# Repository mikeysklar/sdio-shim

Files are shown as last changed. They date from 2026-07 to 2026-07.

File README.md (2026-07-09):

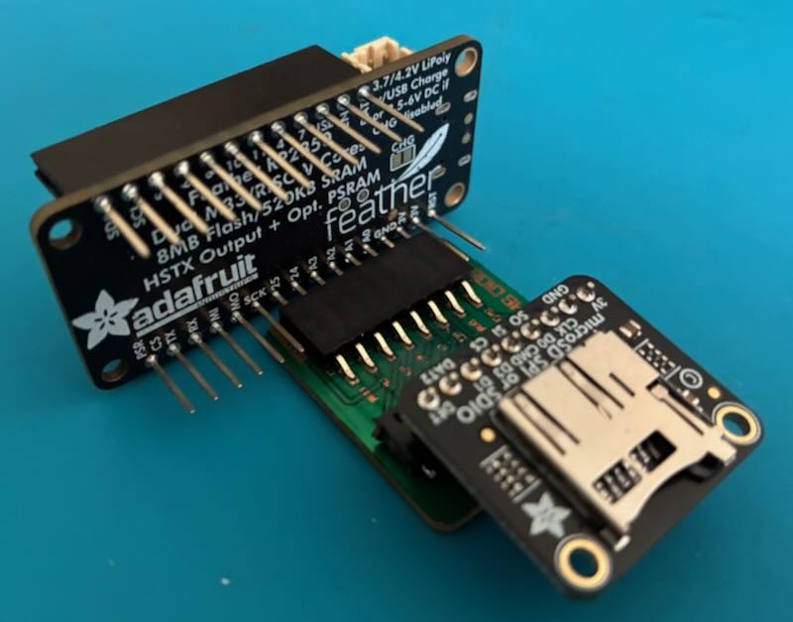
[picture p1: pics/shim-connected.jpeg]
Shim connected to a Feather


# sdio-shim

A direct-connect shim PCB that mates the Adafruit SDIO microSD breakout to a Feather — no breadboard required.

## About

A simple **passive shim** that routes a Feather's analog-rail pins to an SDIO microSD breakout (Adafruit **#4682** or a fork of it), so a stock 4-bit SDIO card hangs off any Feather **without eating the SPI, UART, or I2C buses**.

No active parts. It's a router: Feather header on one side, breakout connector on the other, eight nets between them. The shim itself carries **zero components** — the #4682 already provides the pull-ups, bypass/bulk caps, and card-detect resistor the SDIO spec requires.

Design files are in [`kicad/`](kicad/).

## Feather pinout

Chosen so the six SD logic lines land on **contiguous** Feather positions (A0→D25) while leaving every labeled bus free.

| Feather | GPIO | SDIO signal | Notes |
|---|:----:|---|---|
| 3V | — | Power | |
| GND | — | Ground | |
| A0 | 26 | DAT0 | data block **must stay consecutive** (PIO) |
| A1 | 27 | DAT1 | |
| A2 | 28 | DAT2 | |
| A3 | 29 | DAT3 | |
| D24 | 24 | CLK | any GPIO — placed here to stay on-rail |
| D25 | 25 | CMD | |

**Freed for peripherals:** SCK/MOSI/MISO (GPIO22/23/20 — full SPI bus), TX/RX (GPIO0/1 — UART0), SDA/SCL (I2C, other rail). Card-detect is **dropped** (leave the breakout's DET pad unconnected).

D24/D25 carry CLK/CMD because they sit physically right after A0–A3 on the rail and are plain GPIOs — so the SD wiring stays crossing-free and costs you nothing labeled. TX/RX would work electrically but would burn the UART.

### CircuitPython usage

```python
import board, sdioio, storage
sd = sdioio.SDCard(
    clock=board.D24,
    command=board.D25,
    data=(board.A0, board.A1, board.A2, board.A3),
    frequency=37_500_000,
)
storage.mount(storage.VfsFat(sd), "/sd")
```

## Throughput

Measured bulk transfer over 4-bit SDIO in CircuitPython, using the [Adafruit benchmark setup](https://learn.adafruit.com/microsd-optimization-circuitpython/benchmark-setup). Both boards use this shim with the [Adafruit MicroSD SPI/SDIO breakout (#4682)](https://www.adafruit.com/product/4682).

| Chip | Board | Bus  | Clock (MHz) | Write (MB/s) | Read (MB/s) |
|---|---|---|:---:|:---:|:---:|
| RP2350 | Feather + SDIO Shim  | SDIO | 37.5 | 14.9 | 13.0 |
| ESP32-S3 | Feather + SDIO Shim  | SDIO | 40 | 4.5 | 7.1 |

## Photos & board files

### Assembled
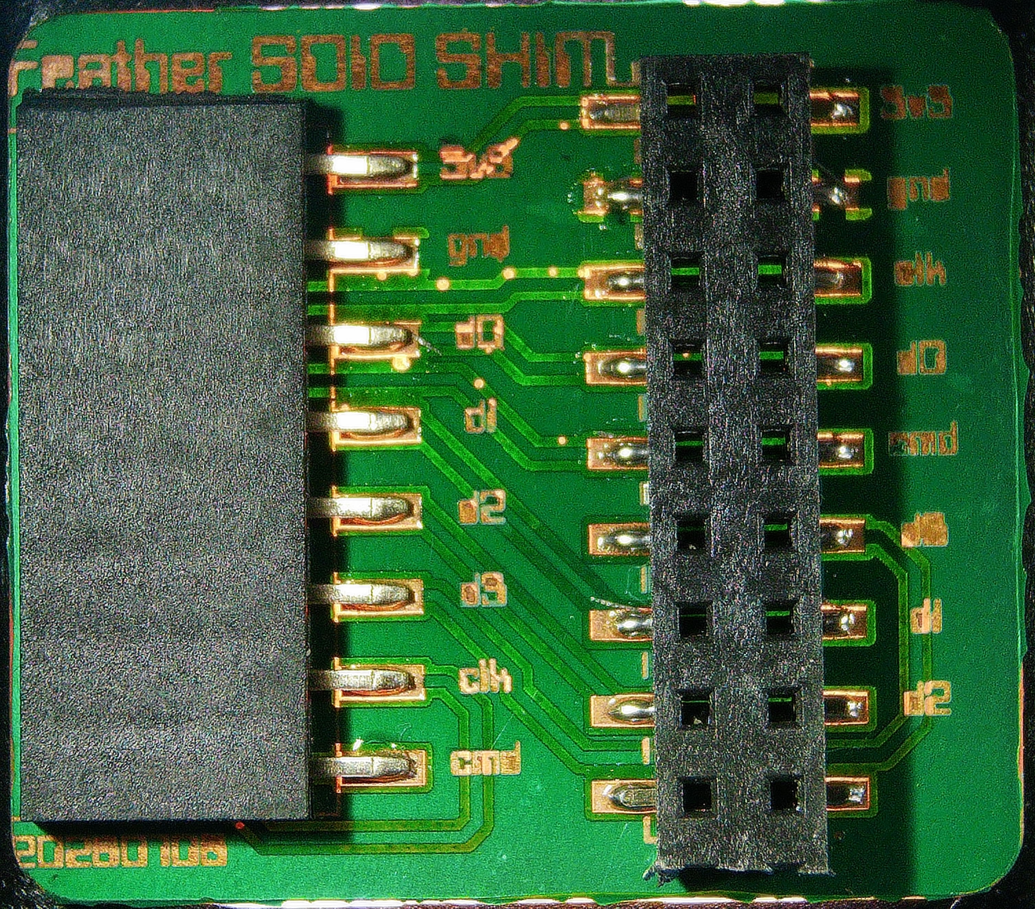
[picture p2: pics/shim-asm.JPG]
Assembled shim with headers


### Blank
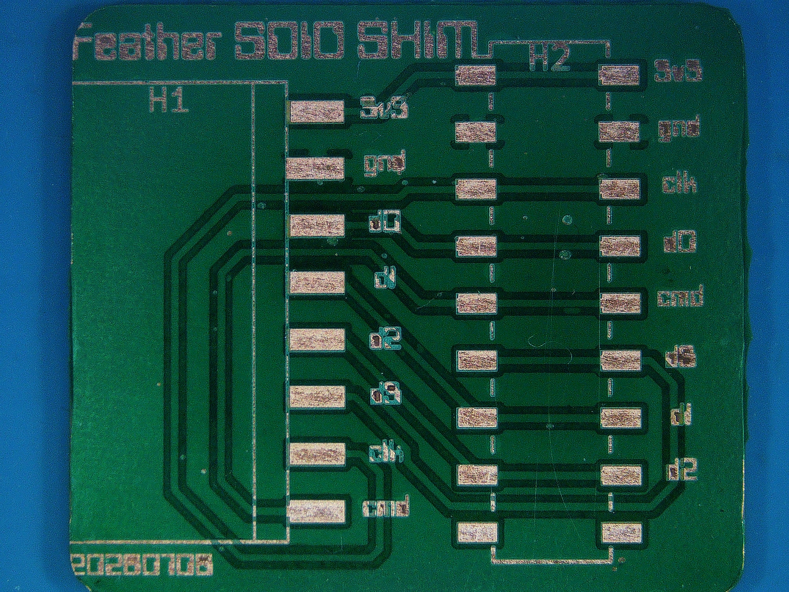
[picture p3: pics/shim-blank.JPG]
Blank fabricated PCB


### PCB
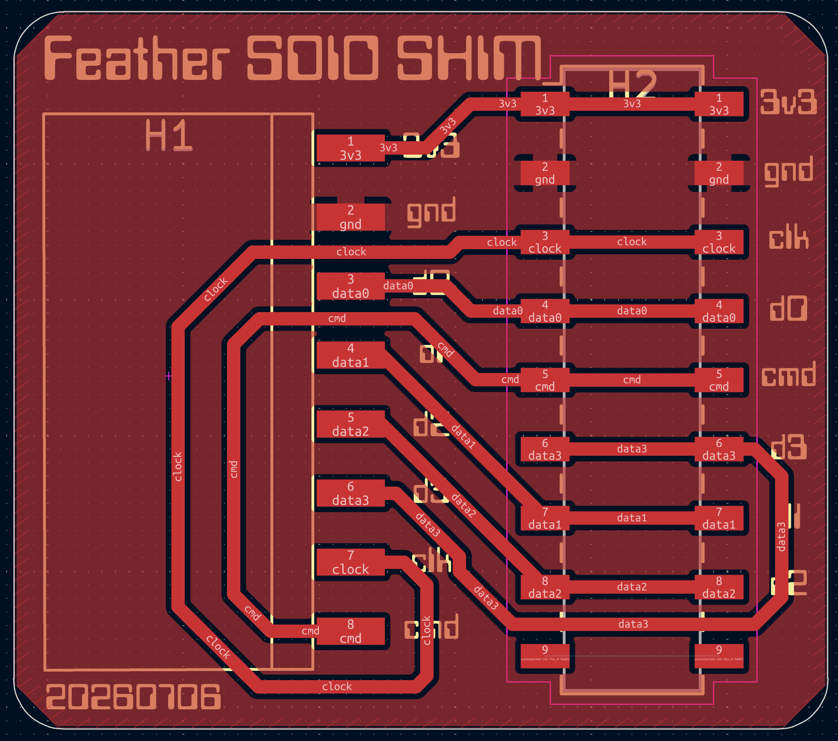
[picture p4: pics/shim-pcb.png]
PCB layout


### Schematic
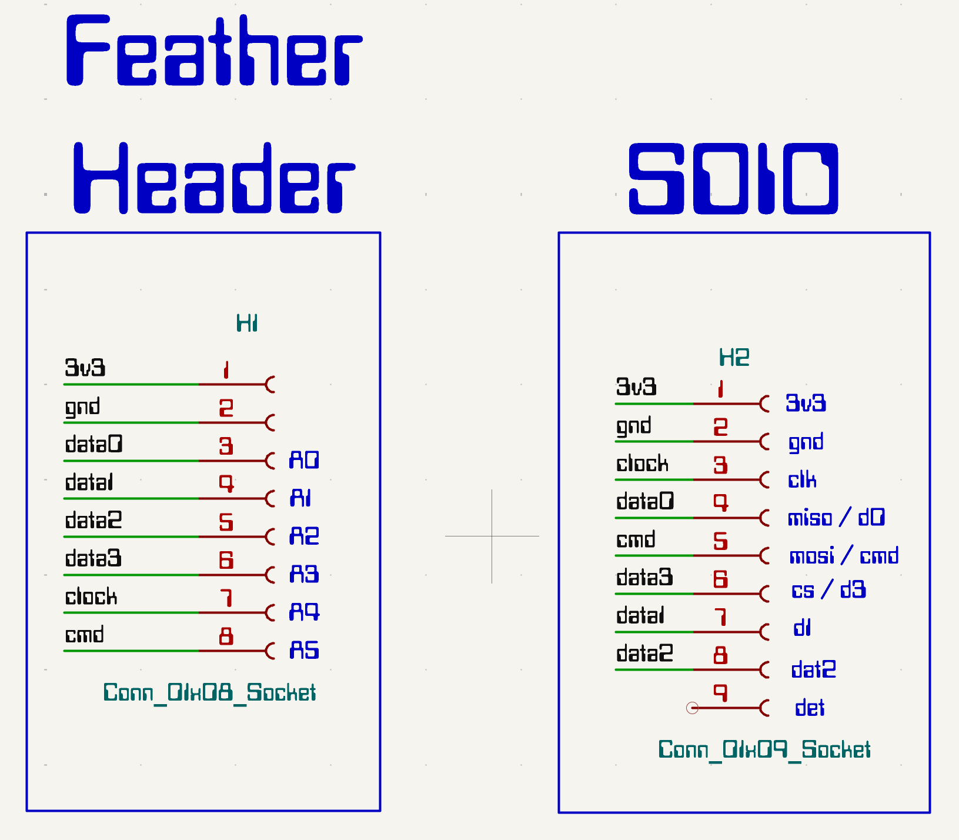
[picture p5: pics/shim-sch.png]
Schematic


## License

[GPLv3](LICENSE)

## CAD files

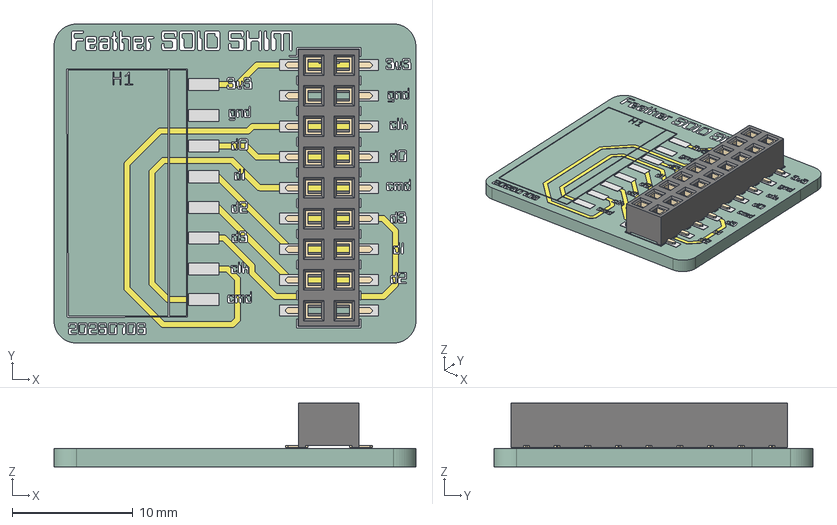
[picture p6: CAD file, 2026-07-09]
kicad/sdio-shim.step
30.0 x 26.4 x 5.29 mm
Wuerth_WR-PHD_610018243021_SMD_2x09_P2.54mm_Vertical
sdio-shim_copper
sdio-shim_pad
sdio-shim_silkscreen
sdio-shim_PCB

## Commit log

2026-07-09 Initial commit: SDIO direct-connect shim for Adafruit SDIO breakout to Feather
    KiCad design files, GPLv3 license, and README.
    [sdio-shim.kicad_pcb, sdio-shim.kicad_sch, sdio-shim.step]
2026-07-09 Add Feather pinout, board photos, and CircuitPython usage to README
2026-07-09 Add SDIO throughput table with clock speeds for RP2350 and ESP32-S3
2026-07-09 Update throughput table with measured RP2350/ESP32-S3 benchmarks and #4682 link
2026-07-09 Remove duplicate mini pinout table under assembled photo
